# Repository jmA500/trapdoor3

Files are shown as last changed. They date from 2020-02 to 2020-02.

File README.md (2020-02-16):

This project describes a 1.8MB/2MB Trapdoor expansion for the Amiga
500. It includes the Schematics and PCB in the Autodesk Eagle format.

For a detailed description of the project including a comprehensive
Theory of operation, refert to:

https://www.jm27.de/amiga-500-trapdoor-extension/

All the files are licensed under the GPLv2, please mention
jmA500@metweb.de as the original author.

Acknowlegements go to Paradroid at the a1k.org/forum and Individual
Computers for useful suggestions.

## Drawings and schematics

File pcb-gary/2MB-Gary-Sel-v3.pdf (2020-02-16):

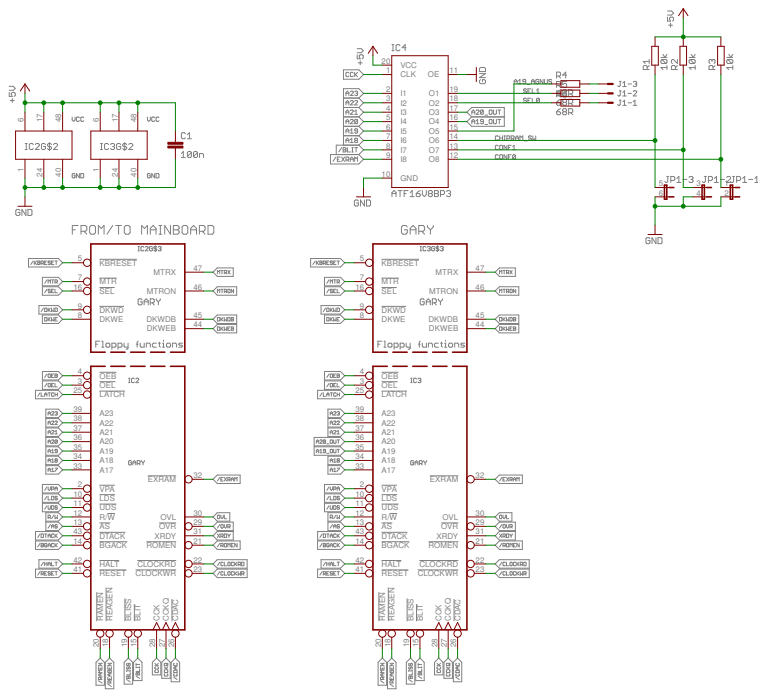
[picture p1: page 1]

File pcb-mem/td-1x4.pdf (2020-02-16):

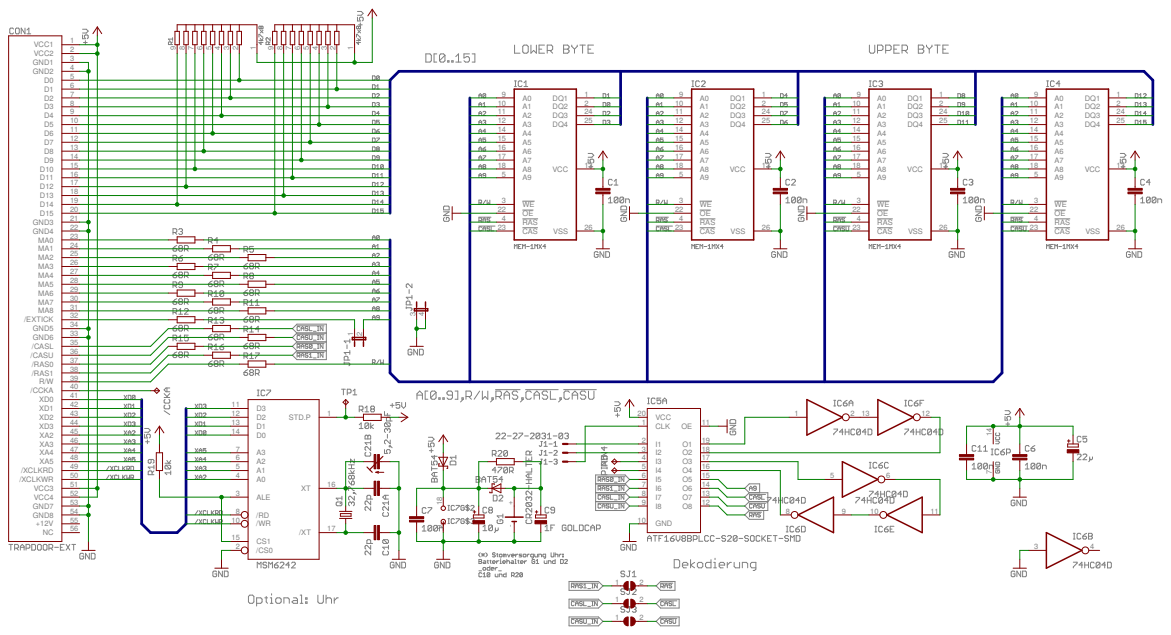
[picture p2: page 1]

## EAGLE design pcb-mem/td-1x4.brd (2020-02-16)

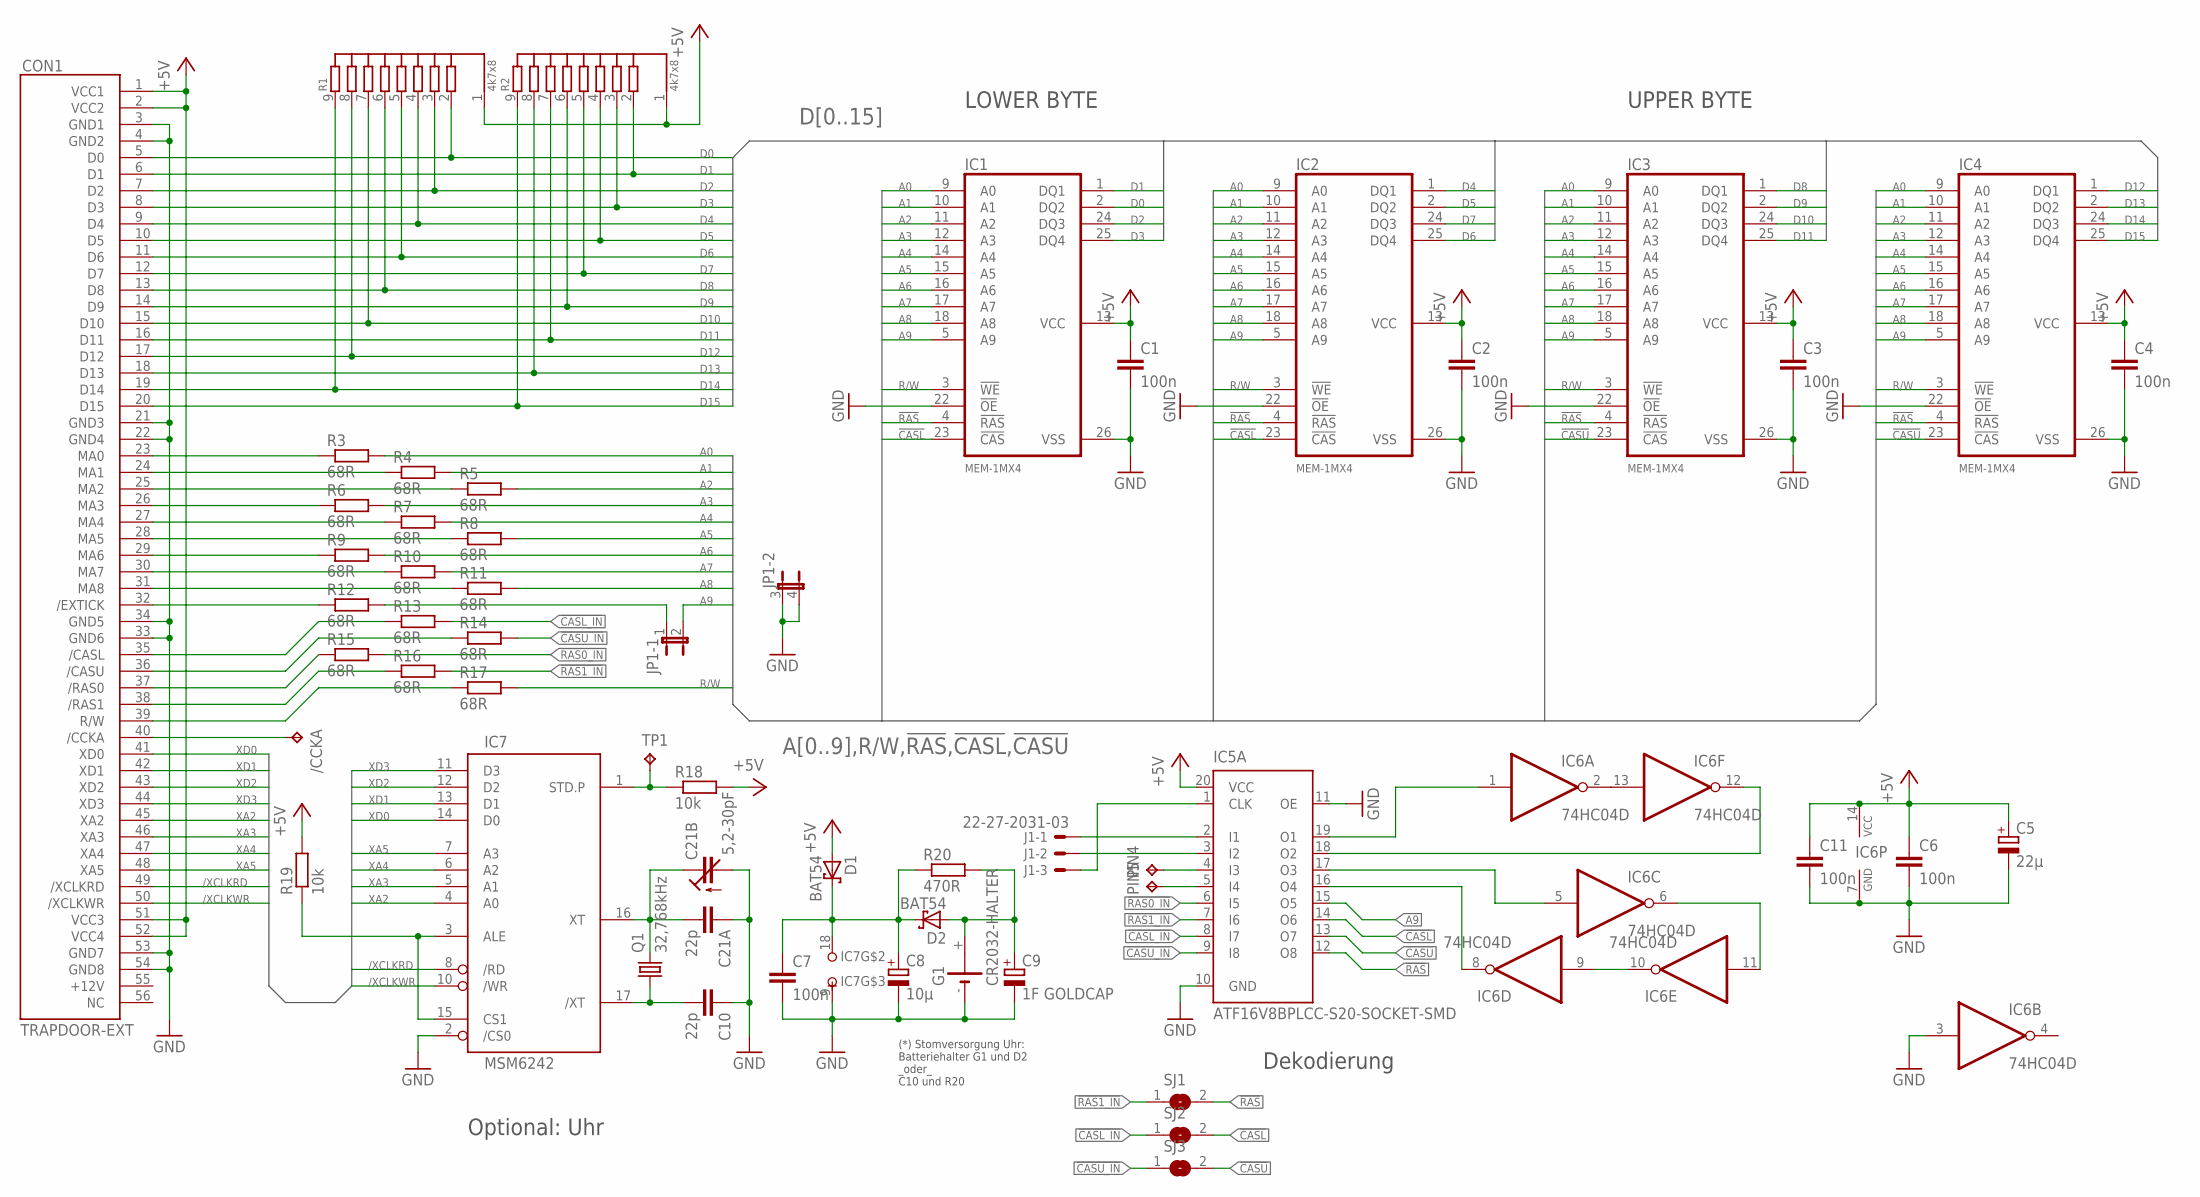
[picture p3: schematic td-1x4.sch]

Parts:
/CCKA: PIN2; B1,27
C1, C2, C3, C4, C6, C7, C11: 100n; C0805
C5: 22µ; SMC_C
C8: 10µ; SMC_A
C9: 1F GOLDCAP; GOLDCAP-5
C10, C21A: 22p; C0805
C21B: 5,2-30pF; CTRIM3050.504
CON1: TRAPDOOR-EXT; 2X28/90
D1, D2: BAT54; SOT23
G1: CR2032-HALTER; HALTER2032
IC1, IC2, IC3, IC4: MEM-1MX4; SOJ26-20
IC5A: ATF16V8BPLCC-S20-SOCKET-SMD; PLCC-S20-SOCKET-SMD
IC6: 74HC04D; SO14
IC7: MSM6242; DIL18
J1: 22-27-2031-03; 6410-03
JP1: JP2QE; JP2Q
PIN4: PIN4; B1,27
PIN5: PIN5; B1,27
Q1: 32,768kHz; TC26V
R1, R2: 4k7x8; RN-9
R3, R4, R5, R6, R7, R8, R9, R10, R11, R12, R13, R14, R15, R16, R17: 68R; R0805
R18, R19: 10k; R0805
R20: 470R; R0805
SJ1, SJ2, SJ3: SJ
TP1: TPB1,27; B1,27

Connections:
!CASL: IC1.23 (!CAS), IC2.23 (!CAS), IC5A.14 (O6), SJ2.2
!CASL_IN: IC5A.8 (I7), R13.2, SJ2.1
!CASU: IC3.23 (!CAS), IC4.23 (!CAS), IC5A.13 (O7), SJ3.2
!CASU_IN: IC5A.9 (I8), R14.2, SJ3.1
!EXRAM: CON1.32 (/EXTICK), R12.1
!RAS: IC1.4 (!RAS), IC2.4 (!RAS), IC3.4 (!RAS), IC4.4 (!RAS), IC5A.12 (O8), SJ1.2
!RAS0_IN: IC5A.6 (I5), R15.2
!RAS1_IN: IC5A.7 (I6), R16.2, SJ1.1
+5V: C1.1, C2.1, C3.1, C4.1, C5.+, C6.1, C11.1, CON1.1 (VCC1), CON1.2 (VCC2), CON1.51 (VCC3), CON1.52 (VCC4), D1.1 (A), IC1.13 (VCC), IC2.13 (VCC), IC3.13 (VCC), IC4.13 (VCC), IC5A.20 (VCC), IC6.14 (VCC), R1.1, R2.1, R18.2, R19.2
/XCLKRD: CON1.49 (/XCLKRD), IC7.8 (/RD)
/XCLKWR: CON1.50 (/XCLKWR), IC7.10 (/WR)
A0: IC1.9 (A0), IC2.9 (A0), IC3.9 (A0), IC4.9 (A0), R3.2
A1: IC1.10 (A1), IC2.10 (A1), IC3.10 (A1), IC4.10 (A1), R4.2
A2: IC1.11 (A2), IC2.11 (A2), IC3.11 (A2), IC4.11 (A2), R5.2
A3: IC1.12 (A3), IC2.12 (A3), IC3.12 (A3), IC4.12 (A3), R6.2
A4: IC1.14 (A4), IC2.14 (A4), IC3.14 (A4), IC4.14 (A4), R7.2
A5: IC1.15 (A5), IC2.15 (A5), IC3.15 (A5), IC4.15 (A5), R8.2
A6: IC1.16 (A6), IC2.16 (A6), IC3.16 (A6), IC4.16 (A6), R9.2
A7: IC1.17 (A7), IC2.17 (A7), IC3.17 (A7), IC4.17 (A7), R10.2
A8: IC1.18 (A8), IC2.18 (A8), IC3.18 (A8), IC4.18 (A8), R11.2
A9: IC1.5 (A9), IC2.5 (A9), IC3.5 (A9), IC4.5 (A9), IC5A.15 (O5), JP1.2
D0: CON1.5 (D0), IC1.2 (DQ2), R1.2
D1: CON1.6 (D1), IC1.1 (DQ1), R2.2
D2: CON1.7 (D2), IC1.24 (DQ3), R1.3
D3: CON1.8 (D3), IC1.25 (DQ4), R2.3
D4: CON1.9 (D4), IC2.1 (DQ1), R1.4
D5: CON1.10 (D5), IC2.2 (DQ2), R2.4
D6: CON1.11 (D6), IC2.25 (DQ4), R1.5
D7: CON1.12 (D7), IC2.24 (DQ3), R2.5
D8: CON1.13 (D8), IC3.1 (DQ1), R1.6
D9: CON1.14 (D9), IC3.2 (DQ2), R2.6
D10: CON1.15 (D10), IC3.24 (DQ3), R1.7
D11: CON1.16 (D11), IC3.25 (DQ4), R2.7
D12: CON1.17 (D12), IC4.1 (DQ1), R1.8
D13: CON1.18 (D13), IC4.2 (DQ2), R2.8
D14: CON1.19 (D14), IC4.24 (DQ3), R1.9
D15: CON1.20 (D15), IC4.25 (DQ4), R2.9
GND: C1.2, C2.2, C3.2, C4.2, C5.-, C6.2, C7.2, C8.-, C9.-, C10.1, C11.2, C21A.1, C21B.2 (A), CON1.3 (GND1), CON1.4 (GND2), CON1.21 (GND3), CON1.22 (GND4), CON1.33 (GND6), CON1.34 (GND5), CON1.53 (GND7), CON1.54 (GND8), G1.-, IC1.22 (!OE), IC1.26 (VSS), IC2.22 (!OE), IC2.26 (VSS), IC3.22 (!OE), IC3.26 (VSS), IC4.22 (!OE), IC4.26 (VSS), IC5A.10 (GND), IC5A.11 (OE), IC6.3 (I), IC6.7 (GND), IC7.2 (/CS0), IC7.9 (-UB), JP1.3 (1), JP1.4 (2)
unnamed: CON1.23 (MA0), R3.1
unnamed: CON1.24 (MA1), R4.1
unnamed: CON1.25 (MA2), R5.1
unnamed: CON1.26 (MA3), R6.1
unnamed: CON1.28 (MA5), R8.1
unnamed: CON1.27 (MA4), R7.1
unnamed: CON1.38 (/RAS1), R16.1
unnamed: CON1.29 (MA6), R9.1
unnamed: CON1.30 (MA7), R10.1
unnamed: CON1.31 (MA8), R11.1
unnamed: CON1.35 (/CASL), R13.1
unnamed: CON1.36 (/CASU), R14.1
unnamed: IC5A.18 (O2), IC6.12 (O)
unnamed: CON1.39 (R/W), R17.1
unnamed: C21A.2, C21B.1 (E), IC7.16 (XT), Q1.2
unnamed: C10.2, IC7.17 (/XT), Q1.1
unnamed: IC7.3 (ALE), IC7.15 (CS1), R19.1
unnamed: IC5A.3 (I2), J1.2
unnamed: IC7.1 (STD.P), R18.1, TP1.TP
unnamed: C9.+, D2.1 (A), G1.+, R20.2
unnamed: C7.1, C8.+, D1.3 (C), D2.3 (C), IC7.18 (+UB), R20.1
unnamed: IC5A.4 (I3), PIN4.TP
unnamed: IC5A.5 (I4), PIN5.TP
unnamed: IC6.9 (I), IC6.10 (O)
unnamed: IC5A.16 (O4), IC6.8 (O)
unnamed: IC5A.17 (O3), IC6.5 (I)
unnamed: CON1.37 (/RAS0), R15.1
unnamed: IC6.2 (O), IC6.13 (I)
unnamed: IC5A.19 (O1), IC6.1 (I)
unnamed: IC5A.1 (CLK), J1.3
unnamed: IC6.6 (O), IC6.11 (I)
unnamed: IC5A.2 (I1), J1.1
unnamed: /CCKA.TP, CON1.40 (/CCKA)
unnamed: JP1.1, R12.2
R/W: IC1.3 (!WE), IC2.3 (!WE), IC3.3 (!WE), IC4.3 (!WE), R17.2
XA2: CON1.45 (XA2), IC7.4 (A0)
XA3: CON1.46 (XA3), IC7.5 (A1)
XA4: CON1.47 (XA4), IC7.6 (A2)
XA5: CON1.48 (XA5), IC7.7 (A3)
XD0: CON1.41 (XD0), IC7.14 (D0)
XD1: CON1.42 (XD1), IC7.13 (D1)
XD2: CON1.43 (XD2), IC7.12 (D2)
XD3: CON1.44 (XD3), IC7.11 (D3)

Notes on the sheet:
LOWER BYTE
UPPER BYTE
Optional: Uhr
Dekodierung
(*) Stomversorgung Uhr: Batteriehalter G1 und D2 _oder_ C10 und R20

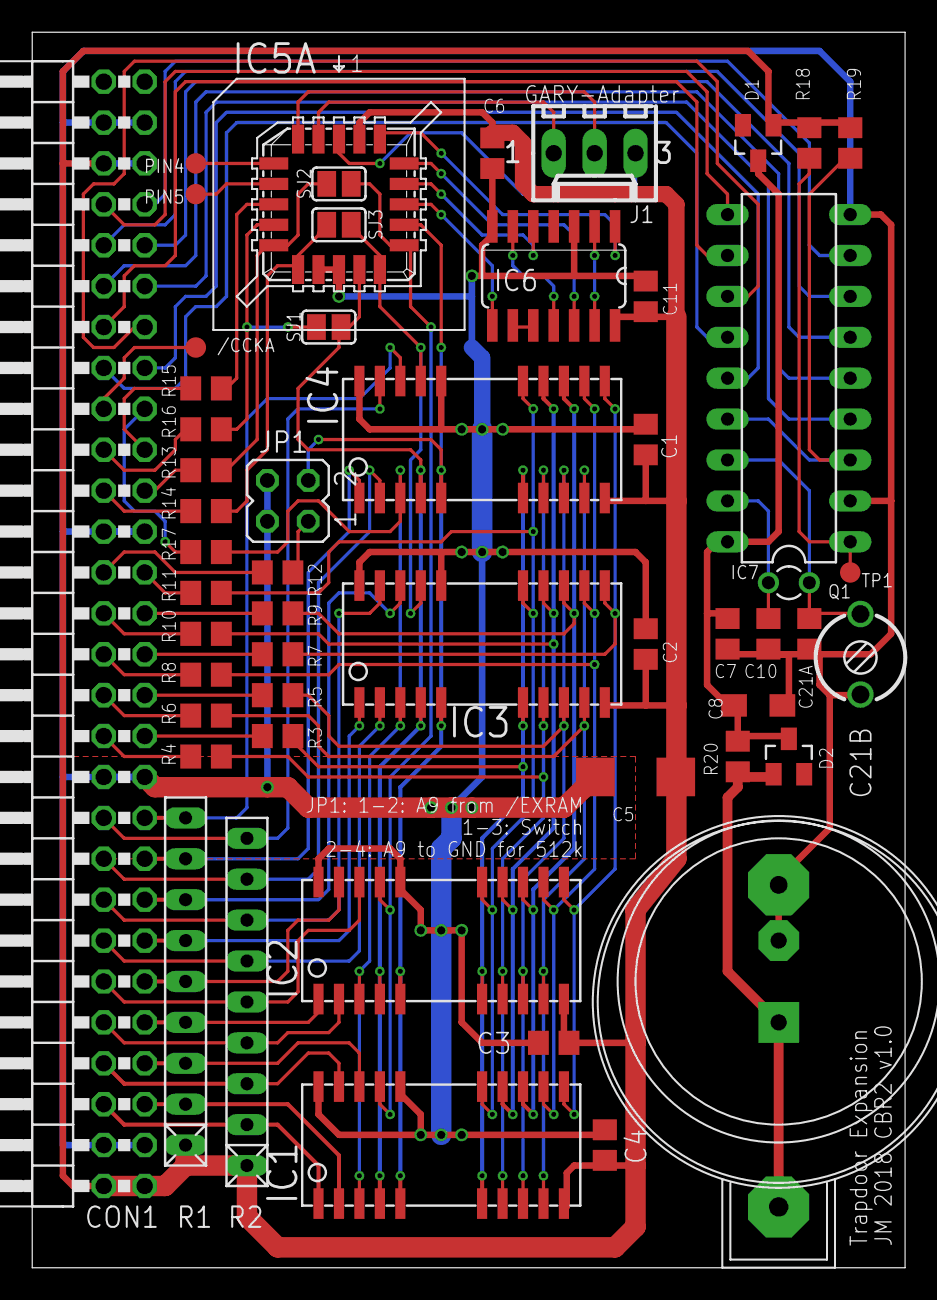
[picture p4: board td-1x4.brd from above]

Board: 2 copper layers, 54.2 x 76.7 mm, 54 parts (0 on the bottom side), 81 nets.

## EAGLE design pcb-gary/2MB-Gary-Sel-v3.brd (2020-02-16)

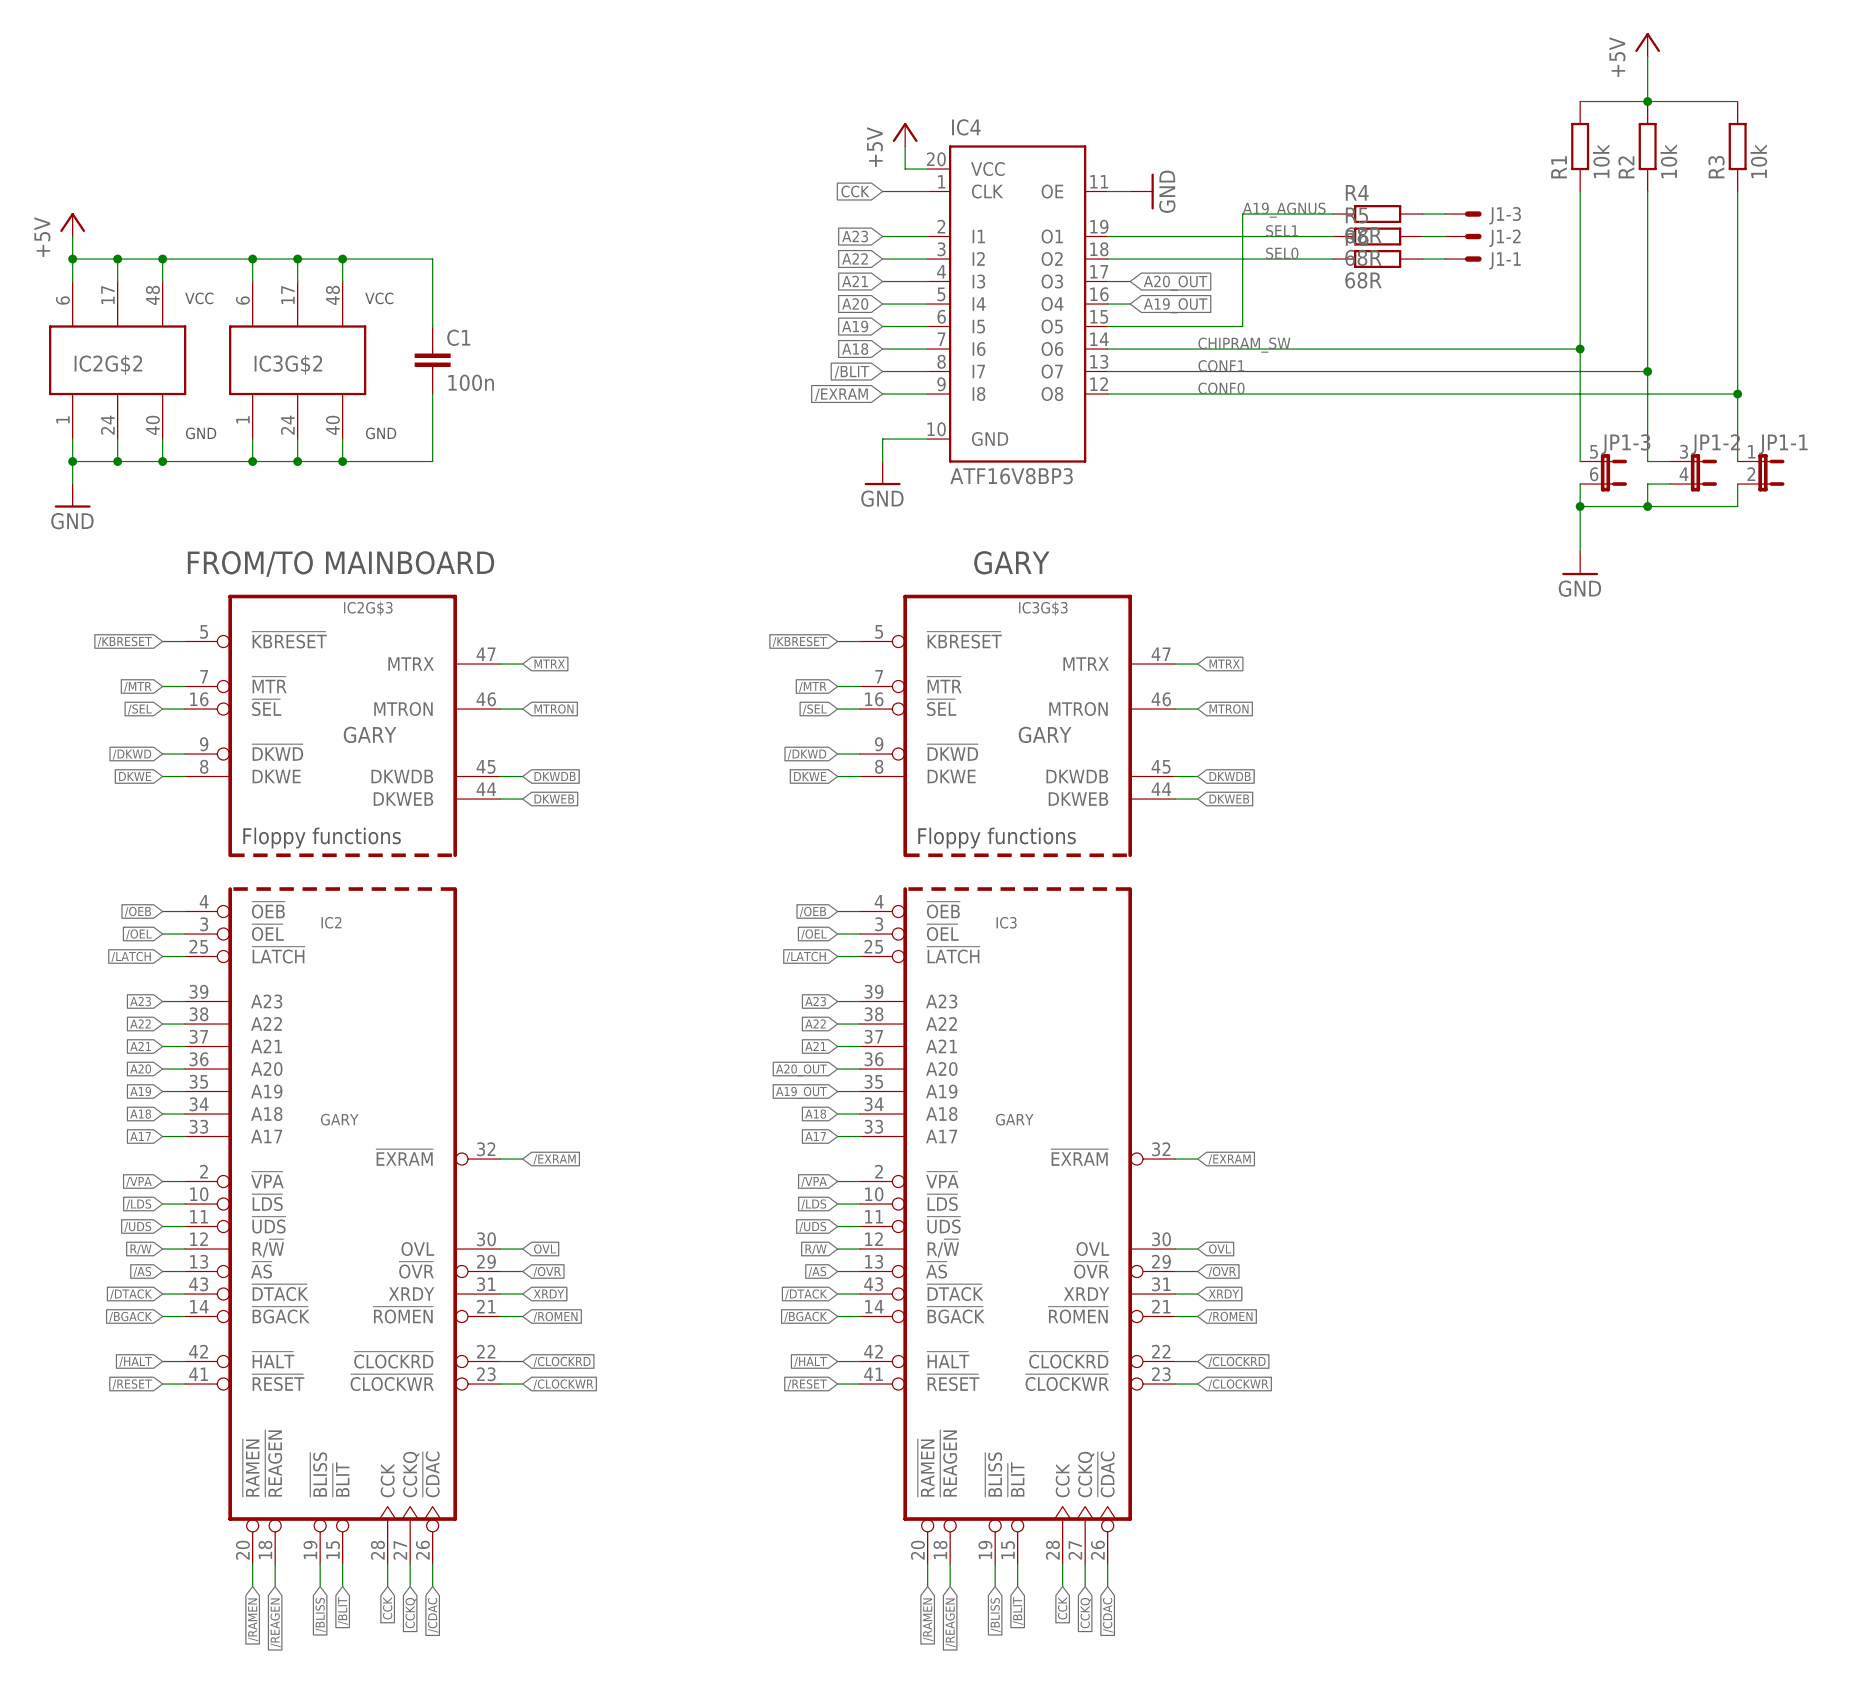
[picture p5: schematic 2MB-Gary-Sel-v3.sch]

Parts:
C1: 100n; C0805
IC2: GARY_SOCKET; DIP48-6NOPLACE
IC3: GARY; DIP48-6
IC4: ATF16V8BP3; DIL20
J1: 22-05-7038-03; 7395-03
JP1: JP3QE; JP3Q
R1, R2, R3: 10k; R0805
R4, R5, R6: 68R; R0805

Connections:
+5V: C1.1, IC2.6 (VCC), IC2.17 (VCC), IC2.48 (VCC), IC3.6 (VCC), IC3.17 (VCC), IC3.48 (VCC), IC4.20 (VCC), R1.2, R2.2, R3.2
/AS: IC2.13 (!AS), IC3.13 (!AS)
/BGACK: IC2.14 (!BGACK), IC3.14 (!BGACK)
/BLISS: IC2.19 (!BLISS), IC3.19 (!BLISS)
/BLIT: IC2.15 (!BLIT), IC3.15 (!BLIT), IC4.8 (I7)
/CDAC: IC2.26 (!CDAC), IC3.26 (!CDAC)
/CLOCKRD: IC2.22 (!CLOCKRD), IC3.22 (!CLOCKRD)
/CLOCKWR: IC2.23 (!CLOCKWR), IC3.23 (!CLOCKWR)
/DKWD: IC2.9 (!DKWD), IC3.9 (!DKWD)
/DTACK: IC2.43 (!DTACK), IC3.43 (!DTACK)
/EXRAM: IC2.32 (!EXRAM), IC3.32 (!EXRAM), IC4.9 (I8)
/HALT: IC2.42 (!HALT), IC3.42 (!HALT)
/KBRESET: IC2.5 (!KBRESET), IC3.5 (!KBRESET)
/LATCH: IC2.25 (!LATCH), IC3.25 (!LATCH)
/LDS: IC2.10 (!LDS), IC3.10 (!LDS)
/MTR: IC2.7 (!MTR), IC3.7 (!MTR)
/OEB: IC2.4 (!OEB), IC3.4 (!OEB)
/OEL: IC2.3 (!OEL), IC3.3 (!OEL)
/OVR: IC2.29 (!OVR), IC3.29 (!OVR)
/RAMEN: IC2.20 (!RAMEN), IC3.20 (!RAMEN)
/REAGEN: IC2.18 (!REAGEN), IC3.18 (!REAGEN)
/RESET: IC2.41 (!RESET), IC3.41 (!RESET)
/ROMEN: IC2.21 (!ROMEN), IC3.21 (!ROMEN)
/SEL: IC2.16 (!SEL), IC3.16 (!SEL)
/UDS: IC2.11 (!UDS), IC3.11 (!UDS)
/VPA: IC2.2 (!VPA), IC3.2 (!VPA)
A17: IC2.33 (A17), IC3.33 (A17)
A18: IC2.34 (A18), IC3.34 (A18), IC4.7 (I6)
A19: IC2.35 (A19), IC4.6 (I5)
A19_AGNUS: IC4.15 (O5), R4.1
A19_OUT: IC3.35 (A19), IC4.16 (O4)
A20: IC2.36 (A20), IC4.5 (I4)
A20_OUT: IC3.36 (A20), IC4.17 (O3)
A21: IC2.37 (A21), IC3.37 (A21), IC4.4 (I3)
A22: IC2.38 (A22), IC3.38 (A22), IC4.3 (I2)
A23: IC2.39 (A23), IC3.39 (A23), IC4.2 (I1)
CCK: IC2.28 (CCK), IC3.28 (CCK), IC4.1 (CLK)
CCKQ: IC2.27 (CCKQ), IC3.27 (CCKQ)
CHIPRAM_SW: IC4.14 (O6), JP1.5 (1), R1.1
CONF0: IC4.12 (O8), JP1.1, R3.1
CONF1: IC4.13 (O7), JP1.3 (1), R2.1
DKWDB: IC2.45 (DKWDB), IC3.45 (DKWDB)
DKWE: IC2.8 (DKWE), IC3.8 (DKWE)
DKWEB: IC2.44 (DKWEB), IC3.44 (DKWEB)
GND: C1.2, IC2.1 (GND), IC2.24 (GND), IC2.40 (GND), IC3.1 (GND), IC3.24 (GND), IC3.40 (GND), IC4.10 (GND), IC4.11 (OE), JP1.2, JP1.4 (2), JP1.6 (2)
MTRON: IC2.46 (MTRON), IC3.46 (MTRON)
MTRX: IC2.47 (MTRX), IC3.47 (MTRX)
unnamed: J1.2, R5.2
unnamed: J1.1, R6.2
unnamed: J1.3, R4.2
OVL: IC2.30 (OVL), IC3.30 (OVL)
R/W: IC2.12 (R/!W!), IC3.12 (R/!W!)
SEL0: IC4.18 (O2), R6.1
SEL1: IC4.19 (O1), R5.1
XRDY: IC2.31 (XRDY), IC3.31 (XRDY)

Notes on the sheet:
FROM/TO MAINBOARD
GARY

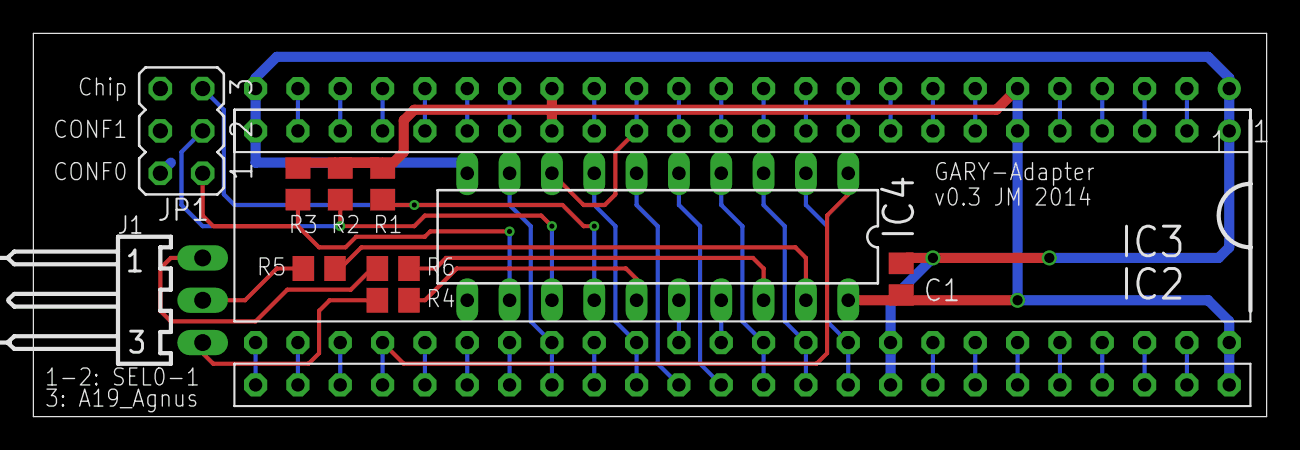
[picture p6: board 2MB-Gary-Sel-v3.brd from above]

Board: 2 copper layers, 74.0 x 23.0 mm, 12 parts (0 on the bottom side), 55 nets.

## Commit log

2020-02-16 Initial commit.
    [2MB-Gary-Sel-v3.brd, 2MB-Gary-Sel-v3.sch, td-1x4.brd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]
2020-02-16 Preparing upload to GitHub
    [td-1x4.brd, td-1x4.sch]
